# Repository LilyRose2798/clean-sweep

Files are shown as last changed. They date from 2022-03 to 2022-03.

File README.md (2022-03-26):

# Clean Sweep

A remix of the [Sweep](https://github.com/davidphilipbarr/Sweep) (based on the original [Ferris](https://github.com/pierrechevalier83/ferris)) that has a tweaked shape and aims to have a cleaner looking design (in particular the layout of the traces).

There are 8 total variations, with each possible combination of the following options:
- Face up or face down MCU (uses Pro Micro or clone with same pinout)
- Straight or rounded traces
- Traces primarily on the front or back of the pcb

All designs include just the left half and are reversible, but keep in mind that reversing the pcb also means the traces will be on the opposite side and the MCU will have to be flipped over, so if you wanted to have both a left and right side with front traces and a face down MCU, then you'd need to make both the face down MCU / back traces version and a face up MCU / front traces version (that you would then flip over to use for the right half).

## Images

### Face Down MCU / Rounded Back Traces - Front View
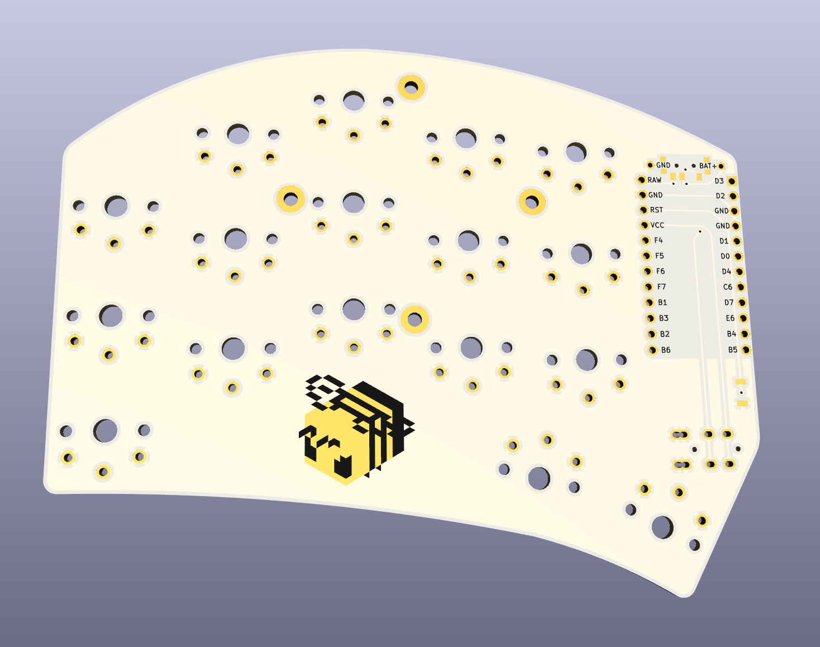
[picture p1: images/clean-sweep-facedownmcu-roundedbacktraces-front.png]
Clean Sweep - Face Down MCU / Rounded Back Traces - Front View


### Face Down MCU / Rounded Back Traces - Back View
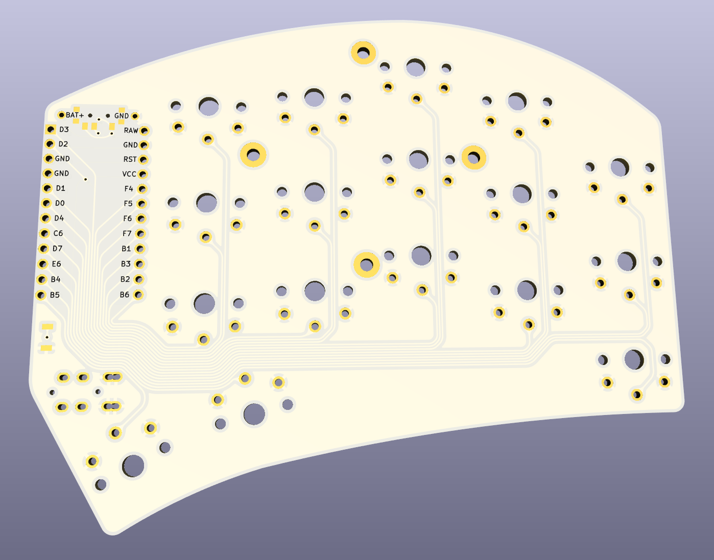
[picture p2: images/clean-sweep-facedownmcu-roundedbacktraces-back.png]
Clean Sweep - Face Down MCU / Rounded Back Traces - Back View


### Face Down MCU / Straight Back Traces - Front View
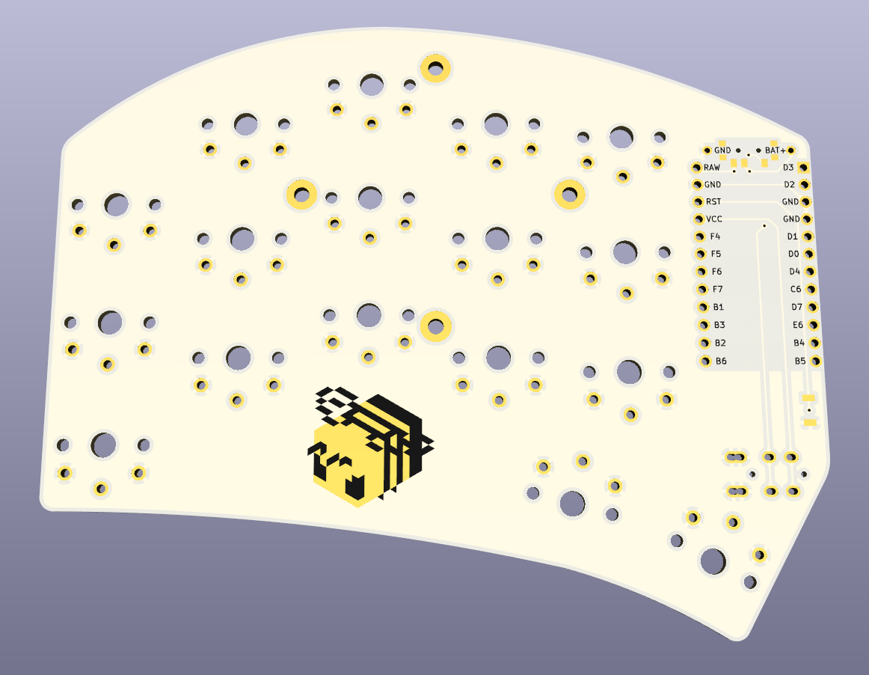
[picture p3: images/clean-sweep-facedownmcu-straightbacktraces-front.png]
Clean Sweep - Face Down MCU / Straight Back Traces - Front View


### Face Down MCU / Straight Back Traces - Back View
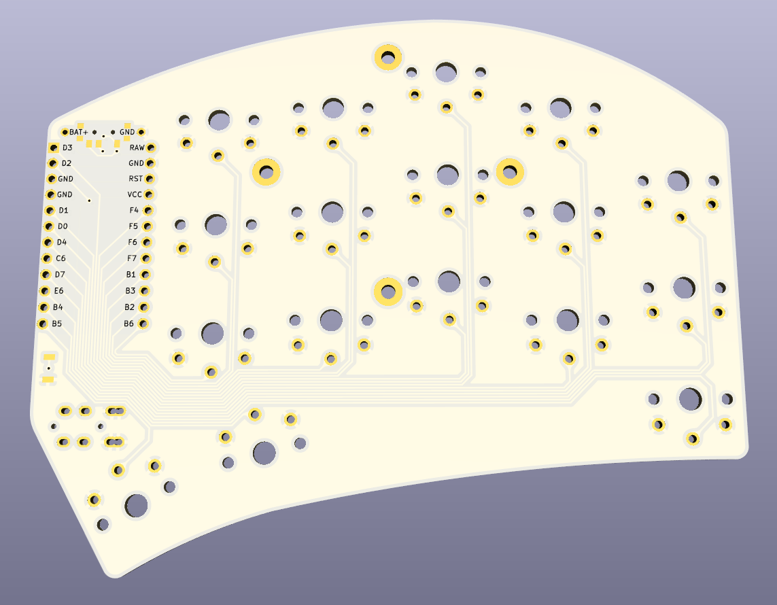
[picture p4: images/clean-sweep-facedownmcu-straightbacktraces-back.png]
Clean Sweep - Face Down MCU / Straight Back Traces - Back View


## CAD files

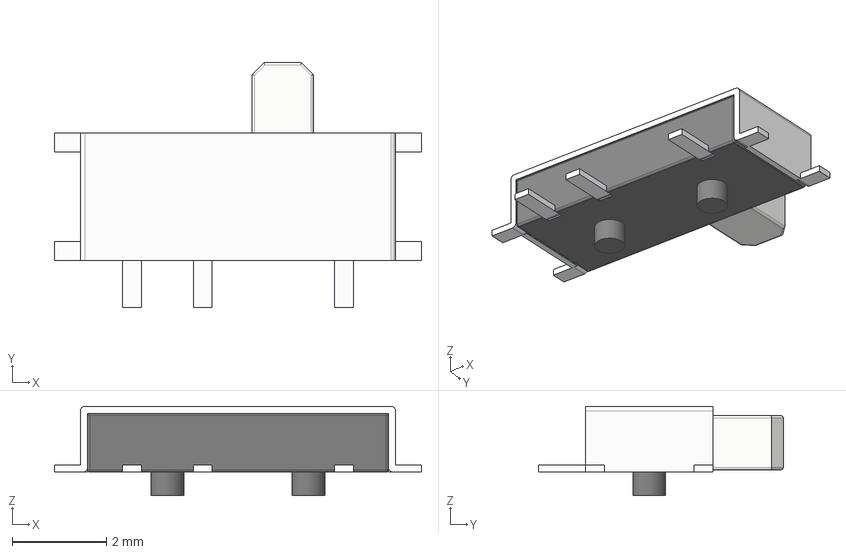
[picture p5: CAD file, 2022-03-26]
models/SW_SPDT_MSK-12C02.step
7.80 x 5.20 x 1.90 mm

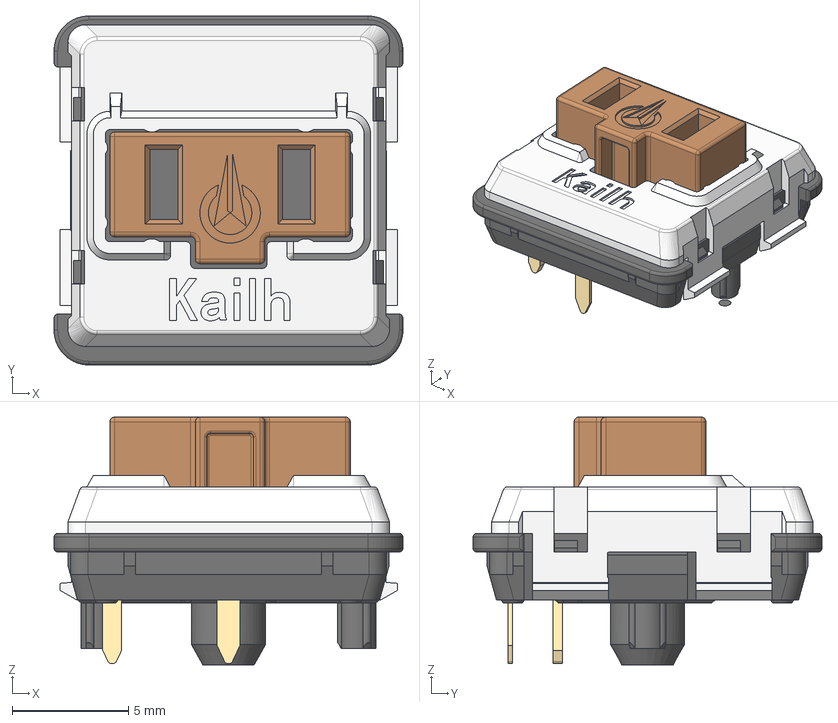
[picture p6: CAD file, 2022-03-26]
models/Kailh-PG1350.step
15.0 x 15.0 x 10.7 mm
Document (1)
Document (2)
Document
Document (3)
Document (4)

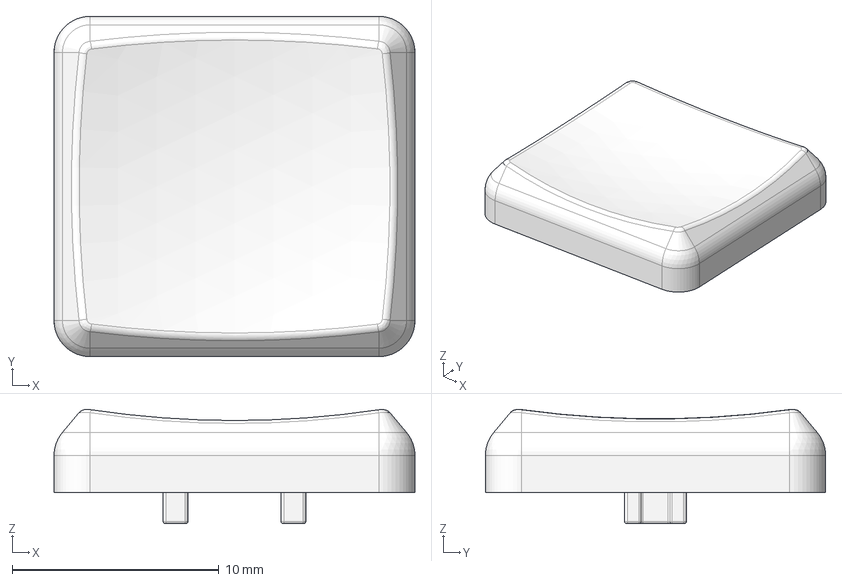
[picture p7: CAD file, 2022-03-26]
models/MBK-Keycap-White.step
17.4 x 16.4 x 5.52 mm

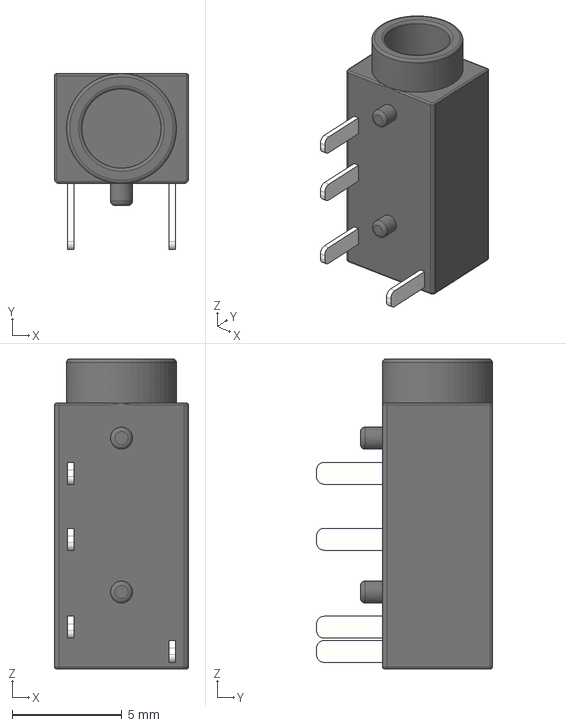
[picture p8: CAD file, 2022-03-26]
models/TRRS-PJ-320A.step
6.10 x 8.00 x 14.1 mm

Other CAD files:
models/MBK-Keycap-Black.step

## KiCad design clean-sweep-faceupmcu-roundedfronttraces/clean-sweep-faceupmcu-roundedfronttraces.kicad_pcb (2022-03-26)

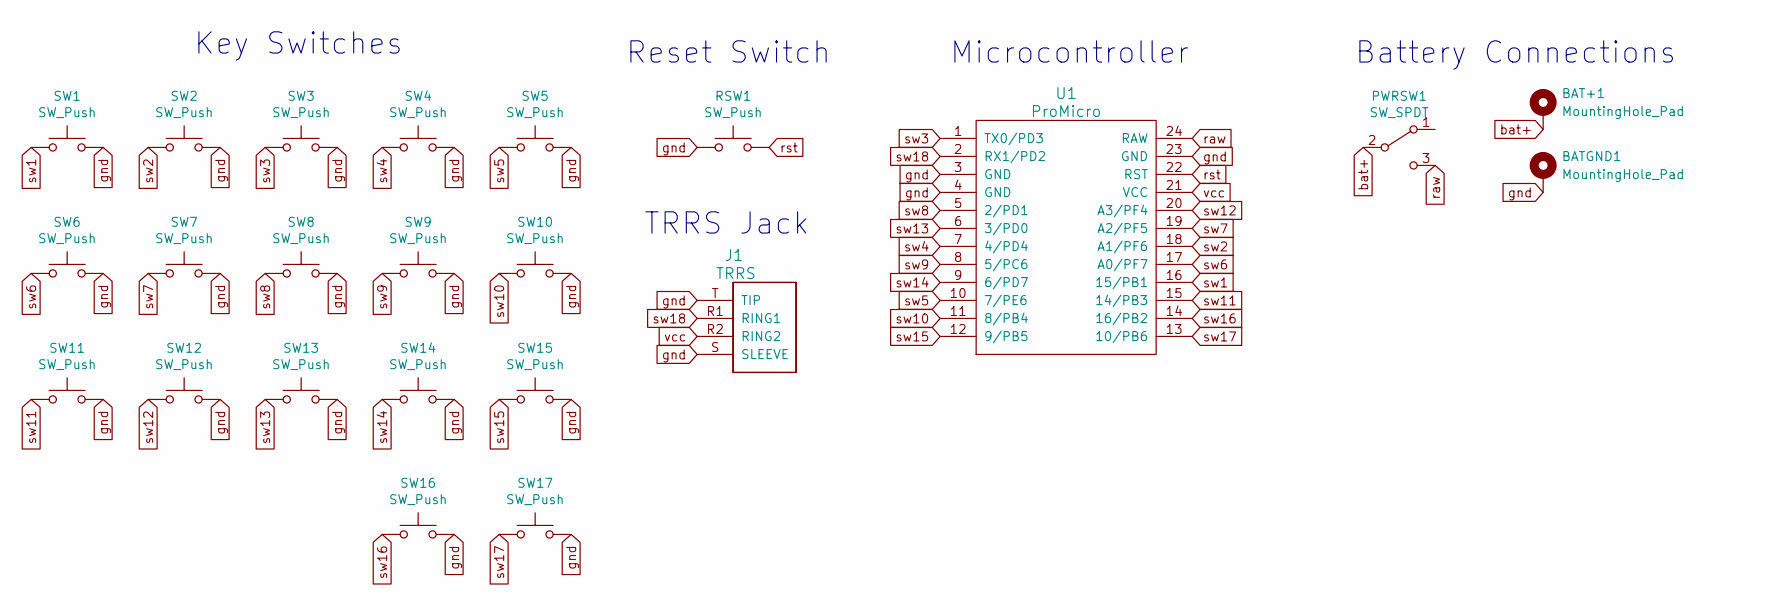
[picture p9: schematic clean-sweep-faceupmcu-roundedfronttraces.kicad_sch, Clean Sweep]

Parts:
BAT+1: MountingHole_Pad; VIA-1.4mm
BATGND1: MountingHole_Pad; VIA-1.4mm
J1: TRRS; TRRS-PJ-320A-reversible
PWRSW1: SW_SPDT; SW_SPDT_MSK-12C02-reversible
RSW1: SW_Push; SW_SPST_B3U-1000P-reversible
SW1, SW2, SW3, SW4, SW5, SW6, SW7, SW8, SW9, SW10, SW11, SW12, SW13, SW14, SW15, SW16, SW17: SW_Push; Kailh-PG1350-1u-reversible
U1: ProMicro

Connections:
bat+: BAT+1.1, PWRSW1.2 (B)
gnd: BATGND1.1, J1.S (SLEEVE), J1.T (TIP), RSW1.1, SW1.2, SW2.2, SW3.2, SW4.2, SW5.2, SW6.2, SW7.2, SW8.2, SW9.2, SW10.2, SW11.2, SW12.2, SW13.2, SW14.2, SW15.2, SW16.2, SW17.2, U1.3 (GND), U1.4 (GND), U1.23 (GND)
raw: PWRSW1.3 (C), U1.24 (RAW)
rst: RSW1.2, U1.22 (RST)
sw1: SW1.1, U1.16 (15/PB1)
sw2: SW2.1, U1.18 (A1/PF6)
sw3: SW3.1, U1.1 (TX0/PD3)
sw4: SW4.1, U1.7 (4/PD4)
sw5: SW5.1, U1.10 (7/PE6)
sw6: SW6.1, U1.17 (A0/PF7)
sw7: SW7.1, U1.19 (A2/PF5)
sw8: SW8.1, U1.5 (2/PD1)
sw9: SW9.1, U1.8 (5/PC6)
sw10: SW10.1, U1.11 (8/PB4)
sw11: SW11.1, U1.15 (14/PB3)
sw12: SW12.1, U1.20 (A3/PF4)
sw13: SW13.1, U1.6 (3/PD0)
sw14: SW14.1, U1.9 (6/PD7)
sw15: SW15.1, U1.12 (9/PB5)
sw16: SW16.1, U1.14 (16/PB2)
sw17: SW17.1, U1.13 (10/PB6)
sw18: J1.R1 (RING1), U1.2 (RX1/PD2)
vcc: J1.R2 (RING2), U1.21 (VCC)

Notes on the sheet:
TRRS Jack
Battery Connections
Key Switches
Reset Switch
Microcontroller

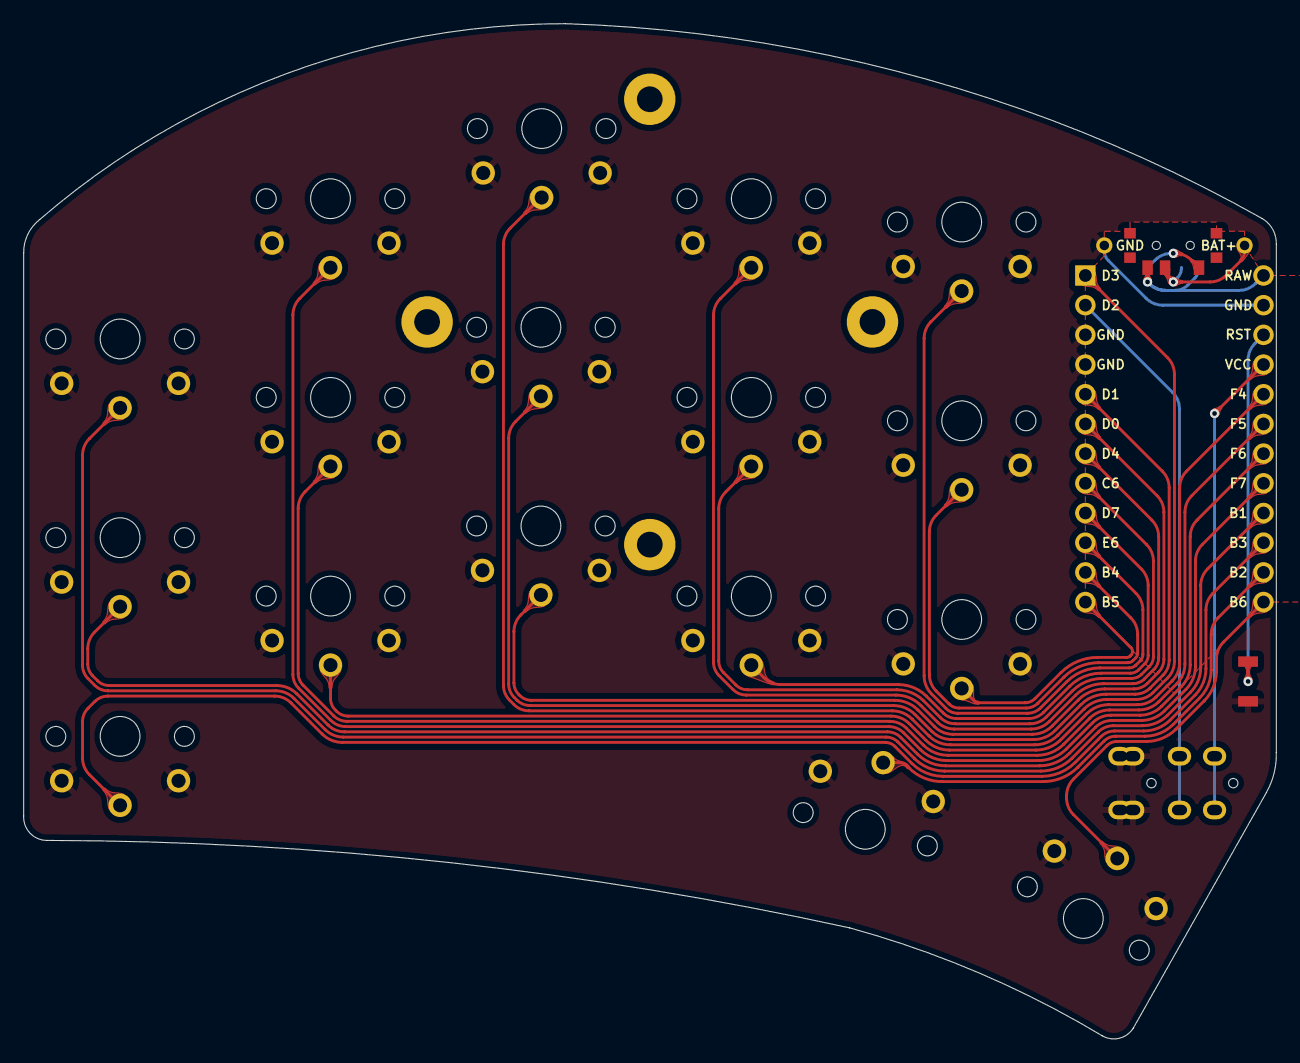
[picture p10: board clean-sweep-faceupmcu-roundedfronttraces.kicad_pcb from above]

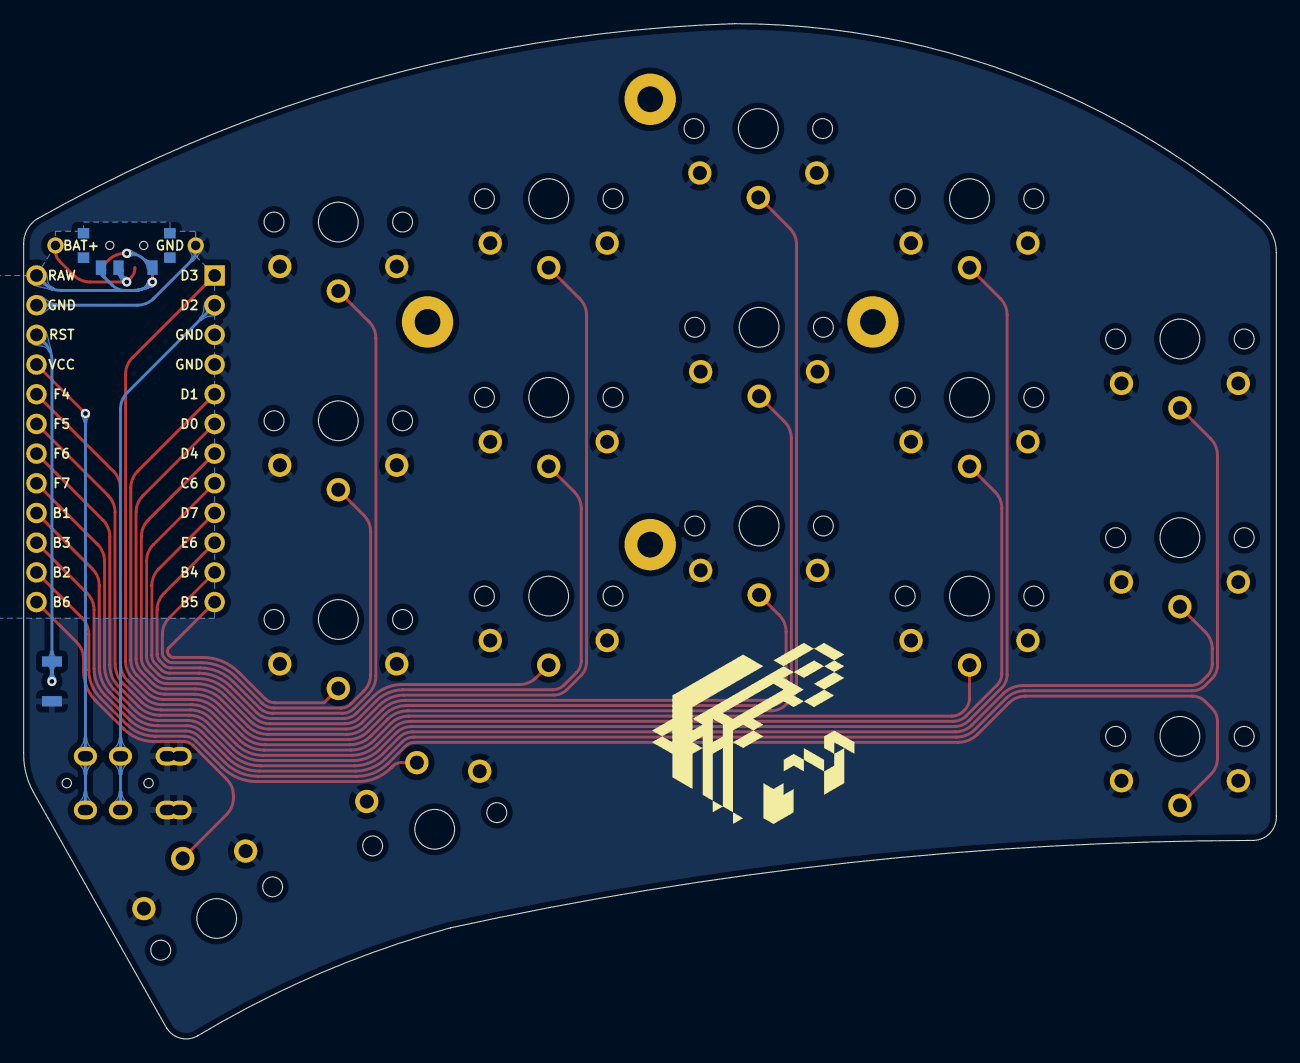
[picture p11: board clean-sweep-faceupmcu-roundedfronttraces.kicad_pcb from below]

Board: 2 copper layers, 107.2 x 86.9 mm, 25 parts (3 on the bottom side), 23 nets.

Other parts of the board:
Bee: G*****; Bee-flipped
TP1: Tenting Puck; TentingPuck

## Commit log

2022-03-26 Add silkscreen labels to battery connection pads
    [clean-sweep-facedownmcu-roundedbacktraces.kicad_pcb, clean-sweep-facedownmcu-roundedfronttraces.kicad_pcb, clean-sweep-facedownmcu-straightbacktraces.kicad_pcb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]
2022-03-26 Update ground fill
    [clean-sweep-faceupmcu-roundedfronttraces.kicad_pcb]
2022-03-26 Update plot config
    [clean-sweep-facedownmcu-roundedbacktraces.kicad_pcb, clean-sweep-facedownmcu-roundedfronttraces.kicad_pcb, clean-sweep-facedownmcu-straightbacktraces.kicad_pcb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]
2022-03-26 Add gerber plots
